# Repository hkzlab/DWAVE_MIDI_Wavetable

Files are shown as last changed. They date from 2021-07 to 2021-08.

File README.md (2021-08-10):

# DWAVE: Dream Wavetable module

## Introduction

The DWAVE is a small General MIDI Synth based on the SAM2695 chip. It can be plugged on the wavetable header of your sound card.

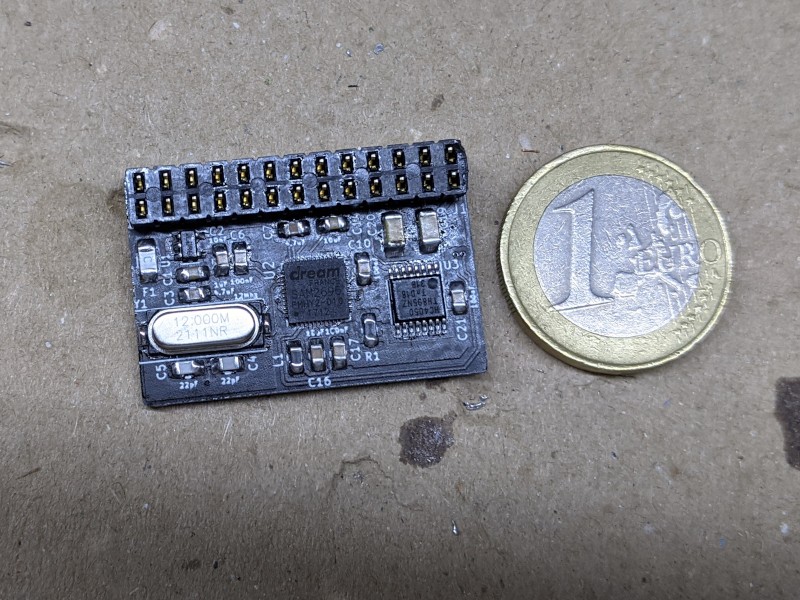
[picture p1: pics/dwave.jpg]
DWAVE


### Disclaimer

I take NO responsibility for what happens if you decide to build and use this card. Your computer might crash, catch fire or be destroyed in other nasty ways.
You're encourauged to take what you deem fit from this, and use it in your projects!

## Bill of Materials

| Component | Qty | Type / Value | Mouser code |
| --- | --- | --- | --- |
| C1 | 2 | 1uF / 0805 | [710-885012207022](https://www.mouser.it/ProductDetail/710-885012207022) |
| C2 | 1 | 10nF / 0805 | [710-885382207006](https://www.mouser.it/ProductDetail/710-885382207006) |
| C3,C7 | 2 | 4.7uF / 0805 | [187-CL21A475KPFNNNG](https://www.mouser.it/ProductDetail/187-CL21A475KPFNNNG) |
| C4,C5 | 2 | 22pF / 0805 | [710-885012007053](https://www.mouser.it/ProductDetail/710-885012007053) |
| C6,C8,C9,C10,C15,C17,C21 | 7 | 100nF / 0805 | [710-885012207072](https://www.mouser.it/ProductDetail/710-885012207072) |
| C14,C16,C18 | 3 | 10uF / 0805 | [187-CL21A106KPFNNNG](https://www.mouser.it/ProductDetail/187-CL21A106KPFNNNG) |
| C19,C20 | 2 | 100uF / 1206 | [81-GRM31CR61A107ME5L](https://www.mouser.it/ProductDetail/81-GRM31CR61A107ME5L) |
| L1 | 1 (or 2)  | Inductor 742792093  | [710-742792093](https://www.mouser.it/ProductDetail/710-742792093) |
| R1 | 1 (or 0)  | 0 ohm or same as L1 | [71-CRCW08050000Z0EAC](https://www.mouser.it/ProductDetail/71-CRCW08050000Z0EAC) |
| R3,R4 | 2 | 47k / 0805 | [652-CR0805FX-4702ELF](https://www.mouser.it/ProductDetail/652-CR0805FX-4702ELF) |
| F1 | 1 | SMD Fuse | [652-SF-1206HI050M-2](https://www.mouser.it/ProductDetail/652-SF-1206HI050M-2) |
| Y1 | 1 | 12Mhz / HC49 | [449-LFXTAL035293REEL](https://www.mouser.it/ProductDetail/449-LFXTAL035293REEL) |
| U1 | 1 | LP2085-3.3 | [926-LP2985IM5X33NOPB](https://www.mouser.it/ProductDetail/926-LP2985IM5X33NOPB) |
| U2 | 1 | SAM2695 | |
| U3 | 1 | 74HC4050 | [771-74HC4050PW-Q100J](https://www.mouser.it/ProductDetail/771-74HC4050PW-Q100J) |
| J1 | 1 | 2x13 2.54mm socket  | [200-SSQ11301GD](https://www.mouser.it/ProductDetail/Samtec/SSQ-113-01-G-D), but any snappable 2.54mm socket is fine |

## Credits

Thanks to [Sergey Kiselev](https://github.com/skiselev) for his symbol/footprint library!

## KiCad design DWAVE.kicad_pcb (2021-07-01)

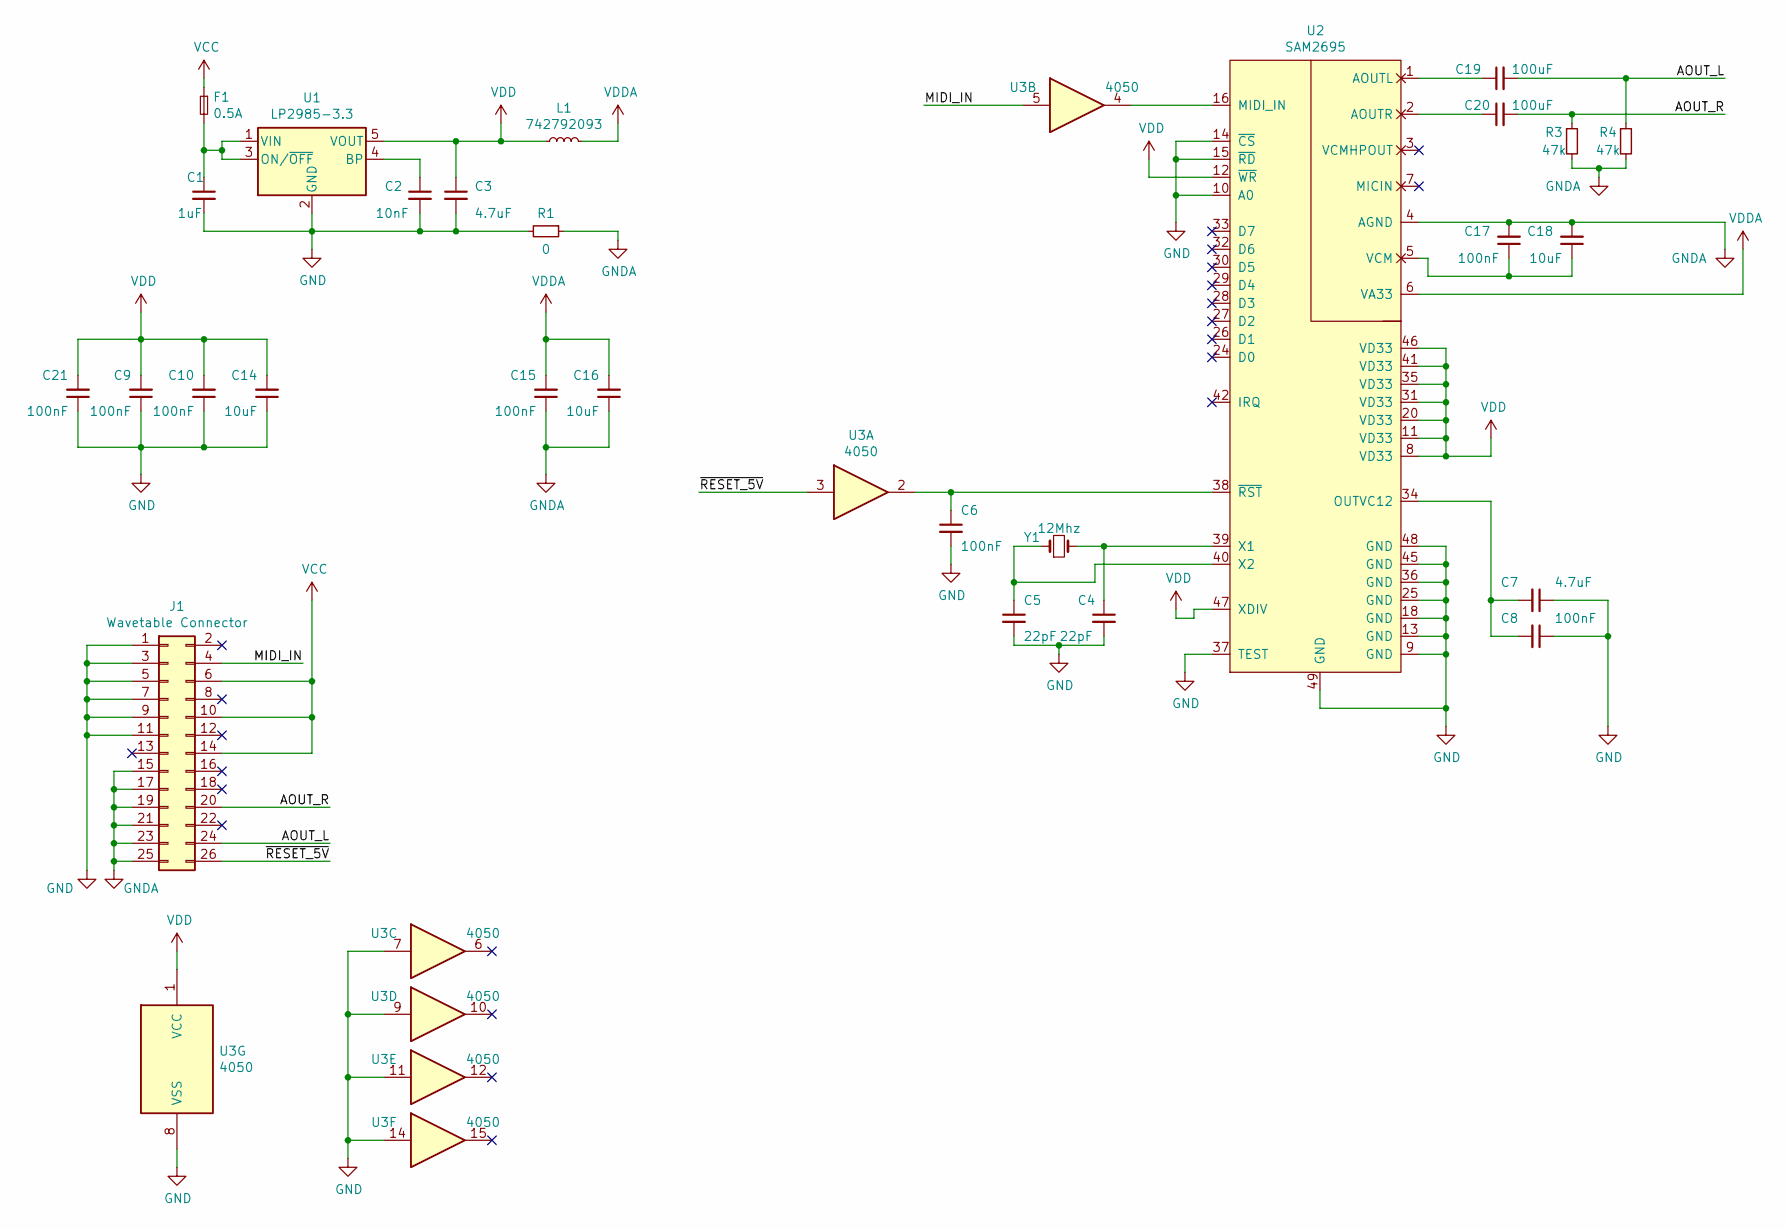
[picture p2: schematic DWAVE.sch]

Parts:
C1: 1uF; C_0805_2012Metric_Pad1.18x1.45mm_HandSolder
C2: 10nF; C_0805_2012Metric_Pad1.18x1.45mm_HandSolder
C3, C7: 4.7uF; C_0805_2012Metric_Pad1.18x1.45mm_HandSolder
C4, C5: 22pF; C_0805_2012Metric_Pad1.18x1.45mm_HandSolder
C6, C8, C9, C10, C15, C17, C21: 100nF; C_0805_2012Metric_Pad1.18x1.45mm_HandSolder
C14, C16, C18: 10uF; C_0805_2012Metric_Pad1.18x1.45mm_HandSolder
C19, C20: 100uF; C_1206_3216Metric_Pad1.33x1.80mm_HandSolder
F1: 0.5A; Fuse_1206_3216Metric_Pad1.42x1.75mm_HandSolder
J1: Wavetable Connector; PinSocket_2x13_P2.54mm_Vertical
L1: 742792093; L_0805_2012Metric_Pad1.15x1.40mm_HandSolder
R1: 0; R_0805_2012Metric_Pad1.20x1.40mm_HandSolder
R3, R4: 47k; R_0805_2012Metric_Pad1.20x1.40mm_HandSolder
U1: LP2985-3.3; SOT-23-5
U2: SAM2695; QFN-48-1EP_6x6mm_P0.4mm_EP4.66x4.66mm_BackHoles
U3: 4050; TSSOP-16_4.4x5mm_P0.65mm
Y1: 12Mhz; Crystal_SMD_HC49-SD

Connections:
/AOUT_L: C19.2, J1.24, R4.1
/AOUT_R: C20.2, J1.20, R3.1
/MIDI_IN: J1.4, U3.5
/~RESET_5V: J1.26, U3.3
GND: C1.2, C2.2, C3.2, C4.2, C5.2, C6.2, C7.1, C8.1, C9.1, C10.1, C14.1, C21.1, J1.1, J1.3, J1.5, J1.7, J1.9, J1.11, R1.2, U1.2 (GND), U2.9 (GND), U2.10 (A0), U2.13 (GND), U2.14 (~CS), U2.15 (~RD), U2.18 (GND), U2.25 (GND), U2.36 (GND), U2.37 (TEST), U2.45 (GND), U2.48 (GND), U2.49 (GND), U3.7, U3.8 (VSS), U3.9, U3.11, U3.14
GNDA: C15.1, C16.1, C17.2, C18.2, J1.15, J1.17, J1.19, J1.21, J1.23, J1.25, R1.1, R3.2, R4.2, U2.4 (AGND)
unnamed: C1.1, F1.2, U1.1 (VIN), U1.3 (ON/~OFF~)
unnamed: C2.1, U1.4 (BP)
unnamed: C4.1, U2.39 (X1), Y1.2
unnamed: C5.1, U2.40 (X2), Y1.1
unnamed: C6.1, U2.38 (~RST), U3.2
unnamed: C7.2, C8.2, U2.34 (OUTVC12)
unnamed: C17.1, C18.1, U2.5 (VCM)
unnamed: C19.1, U2.1 (AOUTL)
unnamed: C20.1, U2.2 (AOUTR)
unnamed: U2.16 (MIDI_IN), U3.4
VCC: F1.1, J1.6, J1.10, J1.14
VDD: C3.1, C9.2, C10.2, C14.2, C21.2, L1.1, U1.5 (VOUT), U2.8 (VD33), U2.11 (VD33), U2.12 (~WR), U2.20 (VD33), U2.31 (VD33), U2.35 (VD33), U2.41 (VD33), U2.46 (VD33), U2.47 (XDIV), U3.1 (VCC)
VDDA: C15.2, C16.2, L1.2, U2.6 (VA33)

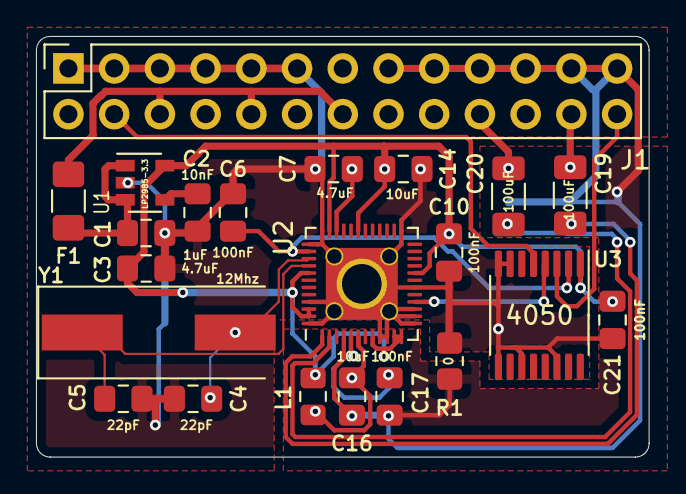
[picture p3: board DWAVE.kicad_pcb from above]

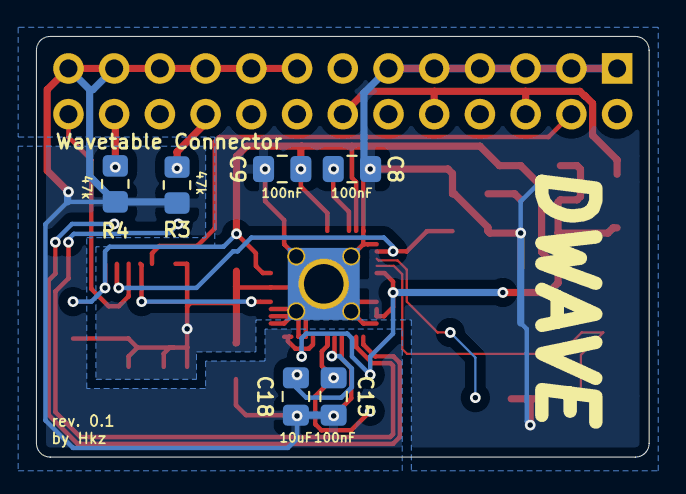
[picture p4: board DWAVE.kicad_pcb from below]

Board: 2 copper layers, 34.0 x 23.4 mm, 28 parts (6 on the bottom side), 19 nets.

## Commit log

2021-05-30 Add basic circuit for midi plug
    [MIDIPLUG.sch]
2021-05-30 Add joystick plug
    [MIDIPLUG.sch]
2021-05-30 Begin placing components
    [MIDIPLUG.kicad_pcb, MIDIPLUG.sch]
2021-05-30 First version of the PCB
    [MIDIPLUG.kicad_pcb, MIDIPLUG.sch]
2021-05-30 Some more connections and tweaks of copper zones
    [MIDIPLUG.kicad_pcb]
2021-05-31 More silkscreen adjustments
    [MIDIPLUG.kicad_pcb]
2021-05-31 Tweak silkscreen
    [MIDIPLUG.kicad_pcb, MIDIPLUG.sch]
2021-05-31 Small changes to silkscreen
    [MIDIPLUG.kicad_pcb]
2021-06-11 Add traces to bottom layer for the heatsink
    [MIDIPLUG.kicad_pcb]
2021-06-11 Change the silkscreen a bit
    [MIDIPLUG.kicad_pcb]
2021-06-11 Change gnd plane
    [MIDIPLUG.kicad_pcb]
2021-06-16 Add hole on underside of SAM chip
    [MIDIPLUG.kicad_pcb, MIDIPLUG.sch]
2021-06-16 Generate gerbers for rev 0.1
    [MIDIPLUG.kicad_pcb]
2021-06-16 Changed footprint
    [MIDIPLUG.kicad_pcb]
2021-07-01 Rewrite the schematics to support waveblaster
    [MIDIPLUG.sch]
2021-07-01 Begin reorganizing board
    [MIDIPLUG.kicad_pcb, MIDIPLUG.sch]
2021-07-01 Routed internal version
    [MIDIPLUG.kicad_pcb]
2021-07-01 Add bypass cap for 4050
    [MIDIPLUG.kicad_pcb, MIDIPLUG.sch]
2021-07-01 Moved around some components
    [MIDIPLUG.kicad_pcb]
2021-07-01 Fixed silkscreen
    [MIDIPLUG.kicad_pcb]
2021-07-01 Changed some things in silkscreen
    [MIDIPLUG.kicad_pcb]
2021-07-01 Add dimensions
    [MIDIPLUG.kicad_pcb]
2021-07-01 Connect GNDA
    [MIDIPLUG.kicad_pcb, MIDIPLUG.sch]
2021-07-01 Add rev 0.1 gerbers
2021-07-01 Add missing mask on backside and redo gerbers
    [MIDIPLUG.kicad_pcb]
2021-08-10 Renamed some filed
    [DWAVE.kicad_pcb, DWAVE.sch]
2021-11-09 Update KiCad URL
